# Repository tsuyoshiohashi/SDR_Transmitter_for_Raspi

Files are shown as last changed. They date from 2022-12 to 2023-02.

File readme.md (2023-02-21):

# Changes
psk_raspi.py : Added pi/2 shift BPSK, pi/4 shift QPSK and OQPSK to the modulation method.

sdr_transmitter_raspy.py : Aligned with the change of psk_raspi.py

readme.md / readme_JP.md : Updated according to the review of the description and the addition of the modulation method.

# SDR Transmitter for Raspi
RaspberryPi and an extension board (All mode transmitter HAT,self-made) perform modulation such as PSK/QPSK with SDR in the 430Mhz band etc. and output high frequency.

## Confirmed environment
Raspi3B+　Raspberry Pi OS(bullseye)

# HAT configuration and operation
## IQ signal
The IQ signal is output to Raspi's I2S and converted to a differential analog signal by the stereo DAC CS4350.
The CS4350 supports up to 192kHz sampling.

In the current version, there is a capacitor in the path of the IQ signal, so it is not possible to send DC.
In other words, it is not possible to send data that has a long series of 0's or 1's.
Usually there is an inversion for bit synchronization, so this shouldn't be a problem.

Also, modulation that requires a DC component cannot be performed.
(For example, BPSK whose phase shift is smaller than 180 degrees)

Since it is IQ modulation, the magnitude of the high frequency output can be changed according to the magnitude of the IQ signal.
The magnitude of the IQ signal can be set by software. (like volume)

If the IQ signal is made too large, it will be distorted, so please use it to make it smaller.

## Modulation/VCO/PLL

TI's trf372017 is used.
According to the datasheet, the trf372017 is an IC chip for 3G/4G with built-in IQ modulator, VCO, and PLL, and can obtain high-frequency signals modulated by IQ signals.
Control of trf372017 is via SPI.

Since the minimum frequency of VCO is 300MHz, transmission in the 144MHz band is not possible. (Upper spec is 4.8GHz, more than enough for me)
The 430MHz band can be transmitted in 10kHz steps.

Please refer to trf372017_PLL.png when changing the transmission frequency and step frequency.
The bandwidth of the IQ modulator is 160MHz, but it is used very little. 192k/160M=0.12%.....

I haven't measured the high frequency output, but it should be less than 10dBm. (P1dB=11dBm)

For details, see the circuit diagram and board diagram.

# Software
You can choose between Gnuradio version and python version for generating and transmitting modulated signals.
they are not the same.

# python version

Run sdr_transmitter_raspi.py from the command line.
~~~
$ python sdr_transmitter_raspy.py
~~~

You can enter commands when the frequency prompt appears. D2 LED will be green if the PLL is locked and red if it is unlocked. The numbers are the frequencies in steps of the transmission frequency.
"help" displays a list of commands.

In the python version, in addition to 10 types from bpsk16kbps to qpsk128kbps, you can choose each speed of pi/2 shift bpsk and pi/4 shift qpsk and OQPSK.

OQPSK is limited to 64kbps due to staggering.

The following is an example of operation.

~~~

$ python sdr_transmitter_raspi.py
SDR Transmitter for Raspi(trf372017) 192k sampling, pi shift Rev.k
SPI BUS: 0  DEV: 0
Execute VCO freq Auto-Calibration: 1
NINT= 43392
43392>data r
Data type: random
43392>len 4096
bit length= 4096
43392>repeat 2
repeat= 2
43392>freq 43393
NINT= 43393
43393>tx bpsk32
modulation type: bpsk32
Tranmit w/ bpsk32 4096 bits 2 times
fs= 192000 sps= 6
bits= 4096 symbols= 4096 samples= 24641 time=  0.12833854166666667
fs= 192000 sps= 6
bits= 4096 symbols= 4096 samples= 24641 time=  0.12833854166666667
43393>tx pi4qpsk64
modulation type: pi4qpsk64
Tranmit w/ pi4qpsk64 4096 bits 2 times
fs= 192000 sps= 6
bits= 4096 symbols= 2048 samples= 12353 time=  0.06433854166666667
fs= 192000 sps= 6
bits= 4096 symbols= 2048 samples= 12353 time=  0.06433854166666667
43393>q
Bye!

~~~

With the current settings, the transmission frequency can be set in 10kHz steps in the 430MHz band. (Integer Mode only)

You can change the frequency and steps by changing the settings, but in that case you may need to change the constants of the circuit. See the trf372017 datasheet for details.

Note that this software does not support read-back of SPI registers and cannot be read.

You can also run psk_raspi.py alone. It does not transmit with trf372017, but displays the IQ waveform etc. See the source for details.

## Gnuradio version

I confirmed the operation with Ver3.8.

Open the flow graph bpsk.grc with Gnuradio. This is a sample to send at bpsk 64kbps.

Set trf372017 such as frequency with EmbeddedBlock(Ctrl trf372017).
Modify the sample project bpsk.grc or copy and paste EmbddedBlock(Ctrl trf372017) in your project.

Send the generated IQ signal to the Audio Sink, and set the Sample Rate to 48kHz, 96kHz, or 192kHz.

3 samples/symbol at 192kHz sampling results in 64k symbols/second.

# Installation instructions

## raspi
1. /boot/config.txt

Edit /boot/config.txt to enable SPI and I2S and enable I2S driver.

Relevant parts of /boot/config.txt
~~~
dtparam=i2s=on
dtoverlay=hifiberry-dac
dtparam=spi=on
~~~

In addition, it is a good idea to disable the headphone jack and HDMI output unless there is a particular reason.
You can make a sound for confirmation, but please turn down the volume.
(The IQ signal is high resolution, but it's not pleasant music! Please be careful not to damage your ears.)

Set the I2S output as the default for the sound device.
You can check the playback device with aplay -l.

If you have multiple playback devices, set the I2S output HifiBerry to default.

2. Module installation

    The python version requires the installation of libraries and modules

~~~
$ sudo apt install libatlas-base-dev 
$ sudo apt install libportaudio2 libportaudiocpp0 portaudio19-dev 
$ pip install spidev matplotlib scikit-commpy pyaudio sounddevice 
~~~

If you have a messege the version of numpy is different

~~~
$ sudo pip install numpy --upgrade 
~~~

For the Gnuradio version, first install Gnuradio.

~~~
sudo apt install gnuradio
~~~

3.8.2 entered in my environment.

Pass PYTHONPATH for Embedded Block.

~~~
$ cd
$ nano .profile
~~~

Add the following at the end (just an example)

~~~
# trf372017 python module path
export PYTHONPATH="/home/hogehoge/sdr_tx:$PYTHONPATH"
~~~ 

The required libraries and modules may differ depending on the environment.

# Execution
    
##  For Gnuradio
Place the necessary files in any directory path set.

Required files:
bpsk.grc epy_block_0.py trf372017_raspi.py

Open bpsk.grc from Gnuradio-Companion and run it.

## For Python

Required files:
sdr_transmitter_raspi.py trf372017_raspi.py psk_raspi.py

Open a terminal and run sdr_transmitter_raspi.py.

~~~
$ python sdr_transmitter_raspi.py
~~~

Once the initialization is complete and the prompt appears, you can enter commands to configure and send.
The command list is displayed by help.
You can use the history function. You will have a .ctrl_trf_history file in your home directory.

Have A Fun!

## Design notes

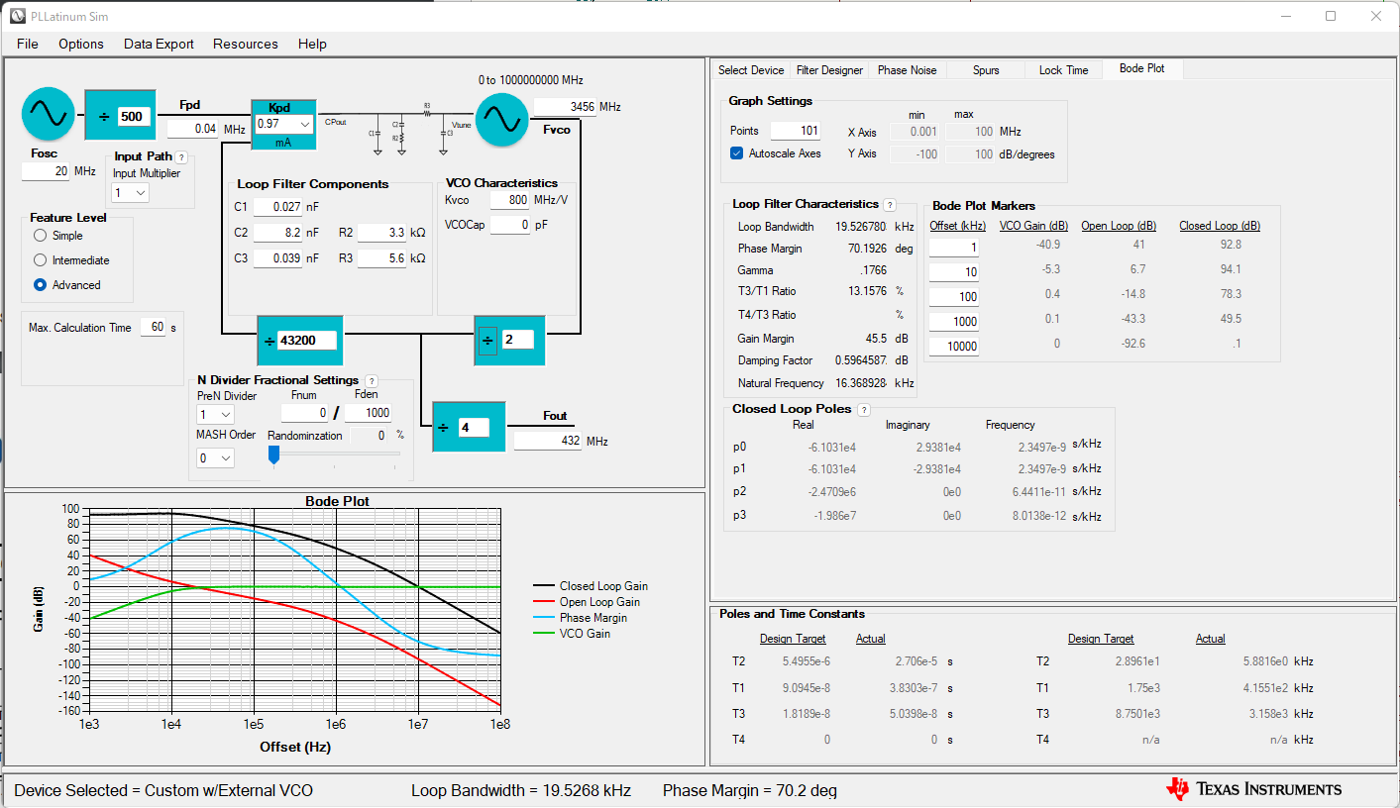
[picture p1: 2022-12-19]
hat/trf372017_PLL.png

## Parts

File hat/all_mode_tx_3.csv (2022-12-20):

Source: | KiCad\6.0\projects\all_mode_tx\all_mode_tx_3\all_mode_tx_3.kicad_sch
Date: | 2022/12/7 8:06
Tool: | Eeschema (6.0.7)
Generator: | C:\Program Files\KiCad\6.0\bin\scripting\plugins/bom_csv_grouped_by_value.py
Component Count: | 123
Individual Components:
Item | Qty | Reference(s) | Value | LibPart | Footprint | Datasheet
 |  | C1 | 10u | Device:C | Capacitor_SMD:C_0603_1608Metric_Pad1.08x0.95mm_HandSolder | ~
 |  | C2 | 104 | Device:C | Capacitor_SMD:C_0603_1608Metric_Pad1.08x0.95mm_HandSolder | ~
 |  | C3 | 10u | Device:C | Capacitor_SMD:C_0603_1608Metric_Pad1.08x0.95mm_HandSolder | ~
 |  | C4 | 104 | Device:C_Small | Capacitor_SMD:C_0603_1608Metric_Pad1.08x0.95mm_HandSolder | ~
 |  | C5 | 104 | Device:C_Small | Capacitor_SMD:C_0603_1608Metric_Pad1.08x0.95mm_HandSolder | ~
 |  | C6 | 104 | Device:C | Capacitor_SMD:C_0603_1608Metric_Pad1.08x0.95mm_HandSolder | ~
 |  | C7 | 104 | Device:C | Capacitor_SMD:C_0603_1608Metric_Pad1.08x0.95mm_HandSolder | ~
 |  | C8 | 474 | Device:C | Capacitor_SMD:C_0603_1608Metric_Pad1.08x0.95mm_HandSolder | ~
 |  | C9 | 2.2p | Device:C | Capacitor_SMD:C_0603_1608Metric_Pad1.08x0.95mm_HandSolder | ~
 |  | C10 | 2.2p | Device:C | Capacitor_SMD:C_0603_1608Metric_Pad1.08x0.95mm_HandSolder | ~
 |  | C11 | 2.7p | Device:C | Capacitor_SMD:C_0603_1608Metric_Pad1.08x0.95mm_HandSolder | ~
 |  | C12 | 2.7p | Device:C | Capacitor_SMD:C_0603_1608Metric_Pad1.08x0.95mm_HandSolder | ~
 |  | C13 | 221 | Device:C | Capacitor_SMD:C_0603_1608Metric_Pad1.08x0.95mm_HandSolder | ~
 |  | C14 | 4.7u | Device:C | Capacitor_SMD:C_0603_1608Metric_Pad1.08x0.95mm_HandSolder | ~
 |  | C15 | 4.7u | Device:C | Capacitor_SMD:C_0603_1608Metric_Pad1.08x0.95mm_HandSolder | ~
 |  | C16 | 4.7u | Device:C | Capacitor_SMD:C_0603_1608Metric_Pad1.08x0.95mm_HandSolder | ~
 |  | C17 | 4.7u | Device:C | Capacitor_SMD:C_0603_1608Metric_Pad1.08x0.95mm_HandSolder | ~
 |  | C18 | 27p | Device:C | Capacitor_SMD:C_0603_1608Metric_Pad1.08x0.95mm_HandSolder | ~
 |  | C19 | 103 | Device:C | Capacitor_SMD:C_0603_1608Metric_Pad1.08x0.95mm_HandSolder | ~
 |  | C20 | 39p | Device:C | Capacitor_SMD:C_0603_1608Metric_Pad1.08x0.95mm_HandSolder | ~
 |  | C21 | 10p | Device:C | Capacitor_SMD:C_0603_1608Metric_Pad1.08x0.95mm_HandSolder | ~
 |  | C22 | 100p | Device:C_Small | Capacitor_SMD:C_0603_1608Metric_Pad1.08x0.95mm_HandSolder | ~
 |  | C23 | 1u | Device:C_Small | Capacitor_SMD:C_0603_1608Metric_Pad1.08x0.95mm_HandSolder | ~
 |  | C24 | 100p | Device:C_Small | Capacitor_SMD:C_0603_1608Metric_Pad1.08x0.95mm_HandSolder | ~
 |  | C25 | 100p | Device:C_Small | Capacitor_SMD:C_0603_1608Metric_Pad1.08x0.95mm_HandSolder | ~
 |  | C26 | 4.7p | Device:C_Small | Capacitor_SMD:C_0603_1608Metric_Pad1.08x0.95mm_HandSolder | ~
 |  | C27 | 102 | Device:C_Small | Capacitor_SMD:C_0603_1608Metric_Pad1.08x0.95mm_HandSolder | ~
 |  | C28 | 4.7p | Device:C_Small | Capacitor_SMD:C_0603_1608Metric_Pad1.08x0.95mm_HandSolder | ~
 |  | C29 | 4.7p | Device:C_Small | Capacitor_SMD:C_0603_1608Metric_Pad1.08x0.95mm_HandSolder | ~
 |  | C30 | 4.7p | Device:C_Small | Capacitor_SMD:C_0603_1608Metric_Pad1.08x0.95mm_HandSolder | ~
 |  | C31 | 100p | Device:C | Capacitor_SMD:C_0603_1608Metric_Pad1.08x0.95mm_HandSolder | ~
 |  | C32 | 100p | Device:C_Small | Capacitor_SMD:C_0603_1608Metric_Pad1.08x0.95mm_HandSolder | ~
 |  | C33 | 4.7p | Device:C_Small | Capacitor_SMD:C_0603_1608Metric_Pad1.08x0.95mm_HandSolder | ~
 |  | C34 | 4.7p | Device:C_Small | Capacitor_SMD:C_0603_1608Metric_Pad1.08x0.95mm_HandSolder | ~
 |  | C35 | 47p | Device:C_Small | Capacitor_SMD:C_0603_1608Metric_Pad1.08x0.95mm_HandSolder | ~
 |  | C36 | 4.7p | Device:C_Small | Capacitor_SMD:C_0603_1608Metric_Pad1.08x0.95mm_HandSolder | ~
 |  | C37 | 1u | Device:C_Small | Capacitor_SMD:C_0603_1608Metric_Pad1.08x0.95mm_HandSolder | ~
 |  | C38 | 1u | Device:C_Small | Capacitor_SMD:C_0603_1608Metric_Pad1.08x0.95mm_HandSolder | ~
 |  | C39 | 1u | Device:C_Small | Capacitor_SMD:C_0603_1608Metric_Pad1.08x0.95mm_HandSolder | ~
 |  | C40 | 10u | Device:C | Capacitor_SMD:C_0603_1608Metric_Pad1.08x0.95mm_HandSolder | ~
 |  | C41 | 3.3 | Device:C | Capacitor_SMD:C_0603_1608Metric_Pad1.08x0.95mm_HandSolder | ~
 |  | C42 | 104 | Device:C | Capacitor_SMD:C_0603_1608Metric_Pad1.08x0.95mm_HandSolder | ~
 |  | C43 | 10u | Device:C | Capacitor_SMD:C_0603_1608Metric_Pad1.08x0.95mm_HandSolder | ~
 |  | C44 | 104 | Device:C | Capacitor_SMD:C_0603_1608Metric_Pad1.08x0.95mm_HandSolder | ~
 |  | C45 | 10u | Device:C | Capacitor_SMD:C_0603_1608Metric_Pad1.08x0.95mm_HandSolder | ~
 |  | C46 | 104 | Device:C | Capacitor_SMD:C_0603_1608Metric_Pad1.08x0.95mm_HandSolder | ~
 |  | C47 | 104 | Device:C | Capacitor_SMD:C_0603_1608Metric_Pad1.08x0.95mm_HandSolder | ~
 |  | D1 | PWR | Device:LED | LED_SMD:LED_0603_1608Metric_Pad1.05x0.95mm_HandSolder | ~
 |  | D2 | LD | Device:LED | LED_SMD:LED_0603_1608Metric_Pad1.05x0.95mm_HandSolder | ~
 |  | FB1 | 1k | Device:FerriteBead_Small | Inductor_SMD:L_0603_1608Metric_Pad1.05x0.95mm_HandSolder | ~
 |  | FB2 | 1k | Device:FerriteBead_Small | Inductor_SMD:L_0603_1608Metric_Pad1.05x0.95mm_HandSolder | ~
 |  | FB3 | 1k | Device:FerriteBead_Small | Inductor_SMD:L_0603_1608Metric_Pad1.05x0.95mm_HandSolder | ~
 |  | FB4 | 1k | Device:FerriteBead_Small | Inductor_SMD:L_0603_1608Metric_Pad1.05x0.95mm_HandSolder | ~
 |  | FB5 | 1k | Device:FerriteBead_Small | Inductor_SMD:L_0603_1608Metric_Pad1.05x0.95mm_HandSolder | ~
 |  | FB6 | 1k | Device:FerriteBead_Small | Inductor_SMD:L_0603_1608Metric_Pad1.05x0.95mm_HandSolder | ~
 |  | FB7 | 1k | Device:FerriteBead_Small | Inductor_SMD:L_0603_1608Metric_Pad1.05x0.95mm_HandSolder | ~
 |  | FB8 | 1k | Device:FerriteBead_Small | Inductor_SMD:L_0603_1608Metric_Pad1.05x0.95mm_HandSolder | ~
 |  | FB9 | DNI | Device:FerriteBead_Small | Inductor_SMD:L_0603_1608Metric_Pad1.05x0.95mm_HandSolder | ~
 |  | J1 | GPIO | Connector_Generic:Conn_02x20_Odd_Even | Connector_PinSocket_2.54mm:PinSocket_2x20_P2.54mm_Vertical | ~
 |  | J2 | SMA | Connector:Conn_Coaxial | Connector_Coaxial:SMA_Molex_73251-1153_EdgeMount_Horizontal | ~
 |  | L1 | 68n | Device:L | Inductor_SMD:L_0603_1608Metric_Pad1.05x0.95mm_HandSolder | ~
 |  | L2 | 68n | Device:L | Inductor_SMD:L_0603_1608Metric_Pad1.05x0.95mm_HandSolder | ~
 |  | L3 | 68n | Device:L | Inductor_SMD:L_0603_1608Metric_Pad1.05x0.95mm_HandSolder | ~
 |  | L4 | 68n | Device:L | Inductor_SMD:L_0603_1608Metric_Pad1.05x0.95mm_HandSolder | ~
 |  | L5 | 10n | Device:L | Inductor_SMD:L_0603_1608Metric_Pad1.05x0.95mm_HandSolder | ~
 |  | L6 | 10n | Device:L | Inductor_SMD:L_0603_1608Metric_Pad1.05x0.95mm_HandSolder | ~
 |  | L7 | 10n | Device:L | Inductor_SMD:L_0603_1608Metric_Pad1.05x0.95mm_HandSolder | ~
 |  | L8 | 10n | Device:L | Inductor_SMD:L_0603_1608Metric_Pad1.05x0.95mm_HandSolder | ~
 |  | Q1 | Q_NMOS_GSD | Device:Q_NMOS_GSD | Package_TO_SOT_SMD:SOT-23 | ~
 |  | R1 | 331 | Device:R | Resistor_SMD:R_0603_1608Metric_Pad0.98x0.95mm_HandSolder | ~
 |  | R2 | 4.7k | Device:R_Small | Resistor_SMD:R_0603_1608Metric_Pad0.98x0.95mm_HandSolder | ~
 |  | R3 | 4.7k | Device:R_Small | Resistor_SMD:R_0603_1608Metric_Pad0.98x0.95mm_HandSolder | ~
 |  | R4 | 4.7k | Device:R_Small | Resistor_SMD:R_0603_1608Metric_Pad0.98x0.95mm_HandSolder | ~
 |  | R5 | 4.7k | Device:R_Small | Resistor_SMD:R_0603_1608Metric_Pad0.98x0.95mm_HandSolder | ~
 |  | R6 | 47 | Device:R | Resistor_SMD:R_0603_1608Metric_Pad0.98x0.95mm_HandSolder | ~
 |  | R7 | 47 | Device:R | Resistor_SMD:R_0603_1608Metric_Pad0.98x0.95mm_HandSolder | ~
 |  | R8 | 47 | Device:R | Resistor_SMD:R_0603_1608Metric_Pad0.98x0.95mm_HandSolder | ~
 |  | R9 | 60.4 | Device:R | Resistor_SMD:R_0603_1608Metric_Pad0.98x0.95mm_HandSolder | ~
 |  | R10 | 60.4 | Device:R | Resistor_SMD:R_0603_1608Metric_Pad0.98x0.95mm_HandSolder | ~
 |  | R11 | 60.4 | Device:R | Resistor_SMD:R_0603_1608Metric_Pad0.98x0.95mm_HandSolder | ~
 |  | R12 | 60.4 | Device:R | Resistor_SMD:R_0603_1608Metric_Pad0.98x0.95mm_HandSolder | ~
 |  | R13 | 0 | Device:R | Resistor_SMD:R_0603_1608Metric_Pad0.98x0.95mm_HandSolder | ~
 |  | R14 | 90.9 | Device:R | Resistor_SMD:R_0603_1608Metric_Pad0.98x0.95mm_HandSolder | ~
 |  | R15 | 90.9 | Device:R | Resistor_SMD:R_0603_1608Metric_Pad0.98x0.95mm_HandSolder | ~
 |  | R16 | 47 | Device:R | Resistor_SMD:R_0603_1608Metric_Pad0.98x0.95mm_HandSolder | ~
 |  | R17 | 47 | Device:R | Resistor_SMD:R_0603_1608Metric_Pad0.98x0.95mm_HandSolder | ~
 |  | R18 | 3.3k | Device:R | Resistor_SMD:R_0603_1608Metric_Pad0.98x0.95mm_HandSolder | ~
 |  | R19 | 2.2k | Device:R_Small | Resistor_SMD:R_0603_1608Metric_Pad0.98x0.95mm_HandSolder | ~
 |  | R20 | 10k | Device:R_Small | Resistor_SMD:R_0603_1608Metric_Pad0.98x0.95mm_HandSolder | ~
 |  | R21 | 5.6k | Device:R | Resistor_SMD:R_0603_1608Metric_Pad0.98x0.95mm_HandSolder | ~
 |  | R22 | 271 | Device:R | Resistor_SMD:R_0603_1608Metric_Pad0.98x0.95mm_HandSolder | ~
 |  | R23 | 50 | Device:R | Resistor_SMD:R_0603_1608Metric_Pad0.98x0.95mm_HandSolder | ~
 |  | R24 | 33 | Device:R | Resistor_SMD:R_0603_1608Metric_Pad0.98x0.95mm_HandSolder | ~
 |  | R25 | 33 | Device:R | Resistor_SMD:R_0603_1608Metric_Pad0.98x0.95mm_HandSolder | ~
 |  | R26 | 33 | Device:R | Resistor_SMD:R_0603_1608Metric_Pad0.98x0.95mm_HandSolder | ~
 |  | R27 | 10k | Device:R | Resistor_SMD:R_0603_1608Metric_Pad0.98x0.95mm_HandSolder | ~
 |  | R28 | 10k | Device:R | Resistor_SMD:R_0603_1608Metric_Pad0.98x0.95mm_HandSolder | ~
 |  | R29 | 10k | Device:R | Resistor_SMD:R_0603_1608Metric_Pad0.98x0.95mm_HandSolder | ~
 |  | R30 | 10k | Device:R | Resistor_SMD:R_0603_1608Metric_Pad0.98x0.95mm_HandSolder | ~
 |  | TP1 | BBI- | Connector:TestPoint | TestPoint:TestPoint_Pad_D2.0mm | ~
 |  | TP2 | BBI+ | Connector:TestPoint | TestPoint:TestPoint_Pad_D2.0mm | ~
 |  | TP3 | BBQ- | Connector:TestPoint | TestPoint:TestPoint_Pad_D2.0mm | ~
 |  | TP4 | BBQ+ | Connector:TestPoint | TestPoint:TestPoint_Pad_D2.0mm | ~
 |  | TP5 | SPILE | Connector:TestPoint | TestPoint:TestPoint_Pad_D2.0mm | ~
 |  | TP6 | SPICLK | Connector:TestPoint | TestPoint:TestPoint_Pad_D2.0mm | ~
 |  | TP7 | SPIDATA | Connector:TestPoint | TestPoint:TestPoint_Pad_D2.0mm | ~
 |  | TP8 | SPIRDBK | Connector:TestPoint | TestPoint:TestPoint_Pad_D2.0mm | ~
 |  | TP9 | PLL_LD | Connector:TestPoint | TestPoint:TestPoint_Pad_D2.0mm | ~
 |  | TP10 | GND | Connector:TestPoint | TestPoint:TestPoint_Pad_D2.5mm | ~
 |  | TP11 | /RST | Connector:TestPoint | TestPoint:TestPoint_Pad_D2.0mm | ~
 |  | TP12 | SDIN | Connector:TestPoint | TestPoint:TestPoint_Pad_D2.0mm | ~
 |  | TP13 | SCLK | Connector:TestPoint | TestPoint:TestPoint_Pad_D2.0mm | ~
 |  | TP14 | LRCK | Connector:TestPoint | TestPoint:TestPoint_Pad_D2.0mm | ~
 |  | TP15 | RMCK | Connector:TestPoint | TestPoint:TestPoint_Pad_D2.0mm | ~
 |  | TP16 | B- | Connector:TestPoint | TestPoint:TestPoint_Pad_D2.0mm | ~
 |  | TP17 | B+ | Connector:TestPoint | TestPoint:TestPoint_Pad_D2.0mm | ~
 |  | TP18 | A- | Connector:TestPoint | TestPoint:TestPoint_Pad_D2.0mm | ~
 |  | TP19 | A+ | Connector:TestPoint | TestPoint:TestPoint_Pad_D2.0mm | ~
 |  | U1 | AZ1117-3.3 | Regulator_Linear:AZ1117-3.3 | Package_TO_SOT_SMD:SOT-223 | https://www.diodes.com/assets/Datasheets/AZ1117.pdf
 |  | U2 | LT6604 | My_Library2:LT6604 | MyLibrary:LT6604IUFF-2.5-PBF
 |  | U3 | TRF372017 | My_Library2:TRF372017 | Package_DFN_QFN:VQFN-48-1EP_7x7mm_P0.5mm_EP5.15x5.15mm_ThermalVias
 |  | U4 | CS4350 | My_Library2:CS4350 | Package_SO:TSSOP-24_4.4x7.8mm_P0.65mm
 |  | X1 | ASV-20.0MHz | Oscillator:ASV-xxxMHz | Oscillator:Oscillator_SMD_Abracon_ASV-4Pin_7.0x5.1mm | http://www.abracon.com/Oscillators/ASV.pdf
Collated Components:
Item | Qty | Reference(s) | Value | LibPart | Footprint | Datasheet
1 | 5 | C1, C3, C40, C43, C45 | 10u | Device:C | Capacitor_SMD:C_0603_1608Metric_Pad1.08x0.95mm_HandSolder | ~
2 | 7 | C2, C6, C7, C42, C44, C46, C47 | 104 | Device:C | Capacitor_SMD:C_0603_1608Metric_Pad1.08x0.95mm_HandSolder | ~
3 | 2 | C4, C5 | 104 | Device:C_Small | Capacitor_SMD:C_0603_1608Metric_Pad1.08x0.95mm_HandSolder | ~
4 | 1 | C8 | 474 | Device:C | Capacitor_SMD:C_0603_1608Metric_Pad1.08x0.95mm_HandSolder | ~
5 | 2 | C9, C10 | 2.2p | Device:C | Capacitor_SMD:C_0603_1608Metric_Pad1.08x0.95mm_HandSolder | ~
6 | 2 | C11, C12 | 2.7p | Device:C | Capacitor_SMD:C_0603_1608Metric_Pad1.08x0.95mm_HandSolder | ~
7 | 1 | C13 | 221 | Device:C | Capacitor_SMD:C_0603_1608Metric_Pad1.08x0.95mm_HandSolder | ~
8 | 4 | C14, C15, C16, C17 | 4.7u | Device:C | Capacitor_SMD:C_0603_1608Metric_Pad1.08x0.95mm_HandSolder | ~
9 | 1 | C18 | 27p | Device:C | Capacitor_SMD:C_0603_1608Metric_Pad1.08x0.95mm_HandSolder | ~
10 | 1 | C19 | 103 | Device:C | Capacitor_SMD:C_0603_1608Metric_Pad1.08x0.95mm_HandSolder | ~
11 | 1 | C20 | 39p | Device:C | Capacitor_SMD:C_0603_1608Metric_Pad1.08x0.95mm_HandSolder | ~
12 | 1 | C21 | 10p | Device:C | Capacitor_SMD:C_0603_1608Metric_Pad1.08x0.95mm_HandSolder | ~
13 | 4 | C22, C24, C25, C32 | 100p | Device:C_Small | Capacitor_SMD:C_0603_1608Metric_Pad1.08x0.95mm_HandSolder | ~
14 | 4 | C23, C37, C38, C39 | 1u | Device:C_Small | Capacitor_SMD:C_0603_1608Metric_Pad1.08x0.95mm_HandSolder | ~
15 | 7 | C26, C28, C29, C30, C33, C34, C36 | 4.7p | Device:C_Small | Capacitor_SMD:C_0603_1608Metric_Pad1.08x0.95mm_HandSolder | ~
16 | 1 | C27 | 102 | Device:C_Small | Capacitor_SMD:C_0603_1608Metric_Pad1.08x0.95mm_HandSolder | ~
17 | 1 | C31 | 100p | Device:C | Capacitor_SMD:C_0603_1608Metric_Pad1.08x0.95mm_HandSolder | ~
18 | 1 | C35 | 47p | Device:C_Small | Capacitor_SMD:C_0603_1608Metric_Pad1.08x0.95mm_HandSolder | ~
19 | 1 | C41 | 3.3 | Device:C | Capacitor_SMD:C_0603_1608Metric_Pad1.08x0.95mm_HandSolder | ~
20 | 1 | D1 | PWR | Device:LED | LED_SMD:LED_0603_1608Metric_Pad1.05x0.95mm_HandSolder | ~
21 | 1 | D2 | LD | Device:LED | LED_SMD:LED_0603_1608Metric_Pad1.05x0.95mm_HandSolder | ~
22 | 8 | FB1, FB2, FB3, FB4, FB5, FB6, FB7, FB8 | 1k | Device:FerriteBead_Small | Inductor_SMD:L_0603_1608Metric_Pad1.05x0.95mm_HandSolder | ~
23 | 1 | FB9 | DNI | Device:FerriteBead_Small | Inductor_SMD:L_0603_1608Metric_Pad1.05x0.95mm_HandSolder | ~
24 | 1 | J1 | GPIO | Connector_Generic:Conn_02x20_Odd_Even | Connector_PinSocket_2.54mm:PinSocket_2x20_P2.54mm_Vertical | ~
25 | 1 | J2 | SMA | Connector:Conn_Coaxial | Connector_Coaxial:SMA_Molex_73251-1153_EdgeMount_Horizontal | ~
26 | 4 | L1, L2, L3, L4 | 68n | Device:L | Inductor_SMD:L_0603_1608Metric_Pad1.05x0.95mm_HandSolder | ~
27 | 4 | L5, L6, L7, L8 | 10n | Device:L | Inductor_SMD:L_0603_1608Metric_Pad1.05x0.95mm_HandSolder | ~
28 | 1 | Q1 | Q_NMOS_GSD | Device:Q_NMOS_GSD | Package_TO_SOT_SMD:SOT-23 | ~
29 | 1 | R1 | 331 | Device:R | Resistor_SMD:R_0603_1608Metric_Pad0.98x0.95mm_HandSolder | ~
30 | 4 | R2, R3, R4, R5 | 4.7k | Device:R_Small | Resistor_SMD:R_0603_1608Metric_Pad0.98x0.95mm_HandSolder | ~
31 | 5 | R6, R7, R8, R16, R17 | 47 | Device:R | Resistor_SMD:R_0603_1608Metric_Pad0.98x0.95mm_HandSolder | ~
32 | 4 | R9, R10, R11, R12 | 60.4 | Device:R | Resistor_SMD:R_0603_1608Metric_Pad0.98x0.95mm_HandSolder | ~
33 | 1 | R13 | 0 | Device:R | Resistor_SMD:R_0603_1608Metric_Pad0.98x0.95mm_HandSolder | ~
34 | 2 | R14, R15 | 90.9 | Device:R | Resistor_SMD:R_0603_1608Metric_Pad0.98x0.95mm_HandSolder | ~
35 | 1 | R18 | 3.3k | Device:R | Resistor_SMD:R_0603_1608Metric_Pad0.98x0.95mm_HandSolder | ~
36 | 1 | R19 | 2.2k | Device:R_Small | Resistor_SMD:R_0603_1608Metric_Pad0.98x0.95mm_HandSolder | ~
37 | 1 | R20 | 10k | Device:R_Small | Resistor_SMD:R_0603_1608Metric_Pad0.98x0.95mm_HandSolder | ~
38 | 1 | R21 | 5.6k | Device:R | Resistor_SMD:R_0603_1608Metric_Pad0.98x0.95mm_HandSolder | ~
39 | 1 | R22 | 271 | Device:R | Resistor_SMD:R_0603_1608Metric_Pad0.98x0.95mm_HandSolder | ~
40 | 1 | R23 | 50 | Device:R | Resistor_SMD:R_0603_1608Metric_Pad0.98x0.95mm_HandSolder | ~
41 | 3 | R24, R25, R26 | 33 | Device:R | Resistor_SMD:R_0603_1608Metric_Pad0.98x0.95mm_HandSolder | ~
42 | 4 | R27, R28, R29, R30 | 10k | Device:R | Resistor_SMD:R_0603_1608Metric_Pad0.98x0.95mm_HandSolder | ~
43 | 1 | TP1 | BBI- | Connector:TestPoint | TestPoint:TestPoint_Pad_D2.0mm | ~
44 | 1 | TP2 | BBI+ | Connector:TestPoint | TestPoint:TestPoint_Pad_D2.0mm | ~
45 | 1 | TP3 | BBQ- | Connector:TestPoint | TestPoint:TestPoint_Pad_D2.0mm | ~
46 | 1 | TP4 | BBQ+ | Connector:TestPoint | TestPoint:TestPoint_Pad_D2.0mm | ~
47 | 1 | TP5 | SPILE | Connector:TestPoint | TestPoint:TestPoint_Pad_D2.0mm | ~
48 | 1 | TP6 | SPICLK | Connector:TestPoint | TestPoint:TestPoint_Pad_D2.0mm | ~
49 | 1 | TP7 | SPIDATA | Connector:TestPoint | TestPoint:TestPoint_Pad_D2.0mm | ~
50 | 1 | TP8 | SPIRDBK | Connector:TestPoint | TestPoint:TestPoint_Pad_D2.0mm | ~
51 | 1 | TP9 | PLL_LD | Connector:TestPoint | TestPoint:TestPoint_Pad_D2.0mm | ~
52 | 1 | TP10 | GND | Connector:TestPoint | TestPoint:TestPoint_Pad_D2.5mm | ~
53 | 1 | TP11 | /RST | Connector:TestPoint | TestPoint:TestPoint_Pad_D2.0mm | ~
54 | 1 | TP12 | SDIN | Connector:TestPoint | TestPoint:TestPoint_Pad_D2.0mm | ~
55 | 1 | TP13 | SCLK | Connector:TestPoint | TestPoint:TestPoint_Pad_D2.0mm | ~
56 | 1 | TP14 | LRCK | Connector:TestPoint | TestPoint:TestPoint_Pad_D2.0mm | ~
57 | 1 | TP15 | RMCK | Connector:TestPoint | TestPoint:TestPoint_Pad_D2.0mm | ~
58 | 1 | TP16 | B- | Connector:TestPoint | TestPoint:TestPoint_Pad_D2.0mm | ~
59 | 1 | TP17 | B+ | Connector:TestPoint | TestPoint:TestPoint_Pad_D2.0mm | ~
60 | 1 | TP18 | A- | Connector:TestPoint | TestPoint:TestPoint_Pad_D2.0mm | ~
61 | 1 | TP19 | A+ | Connector:TestPoint | TestPoint:TestPoint_Pad_D2.0mm | ~
62 | 1 | U1 | AZ1117-3.3 | Regulator_Linear:AZ1117-3.3 | Package_TO_SOT_SMD:SOT-223 | https://www.diodes.com/assets/Datasheets/AZ1117.pdf
63 | 1 | U2 | LT6604 | My_Library2:LT6604 | MyLibrary:LT6604IUFF-2.5-PBF
64 | 1 | U3 | TRF372017 | My_Library2:TRF372017 | Package_DFN_QFN:VQFN-48-1EP_7x7mm_P0.5mm_EP5.15x5.15mm_ThermalVias
65 | 1 | U4 | CS4350 | My_Library2:CS4350 | Package_SO:TSSOP-24_4.4x7.8mm_P0.65mm
66 | 1 | X1 | ASV-20.0MHz | Oscillator:ASV-xxxMHz | Oscillator:Oscillator_SMD_Abracon_ASV-4Pin_7.0x5.1mm | http://www.abracon.com/Oscillators/ASV.pdf

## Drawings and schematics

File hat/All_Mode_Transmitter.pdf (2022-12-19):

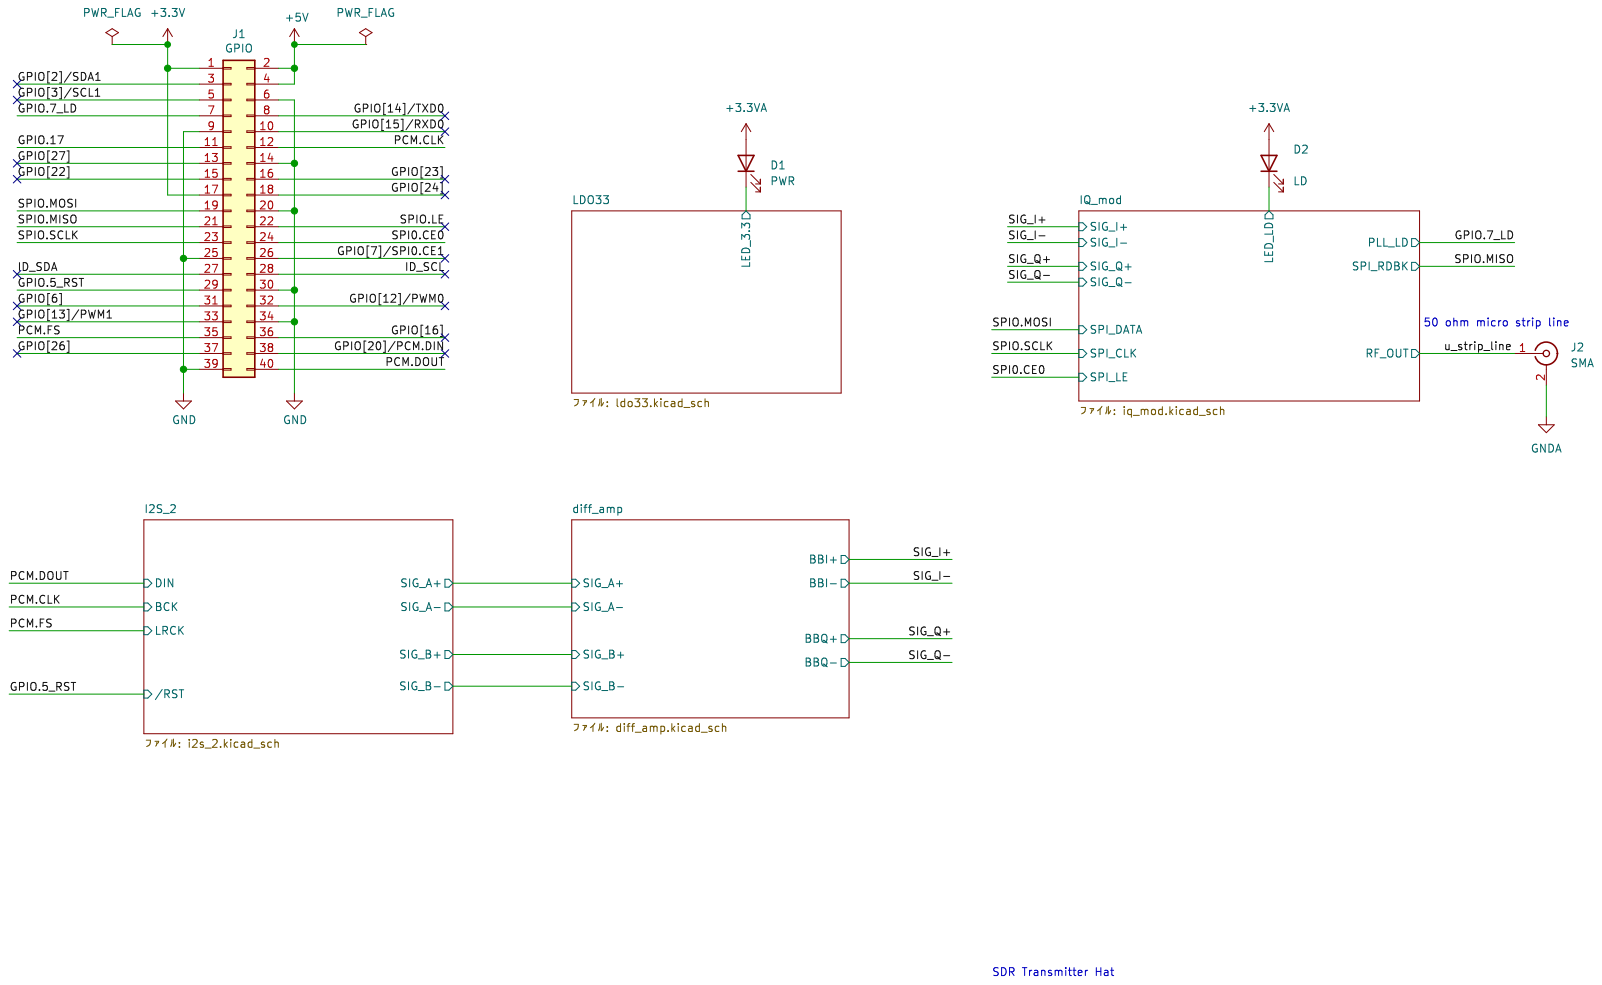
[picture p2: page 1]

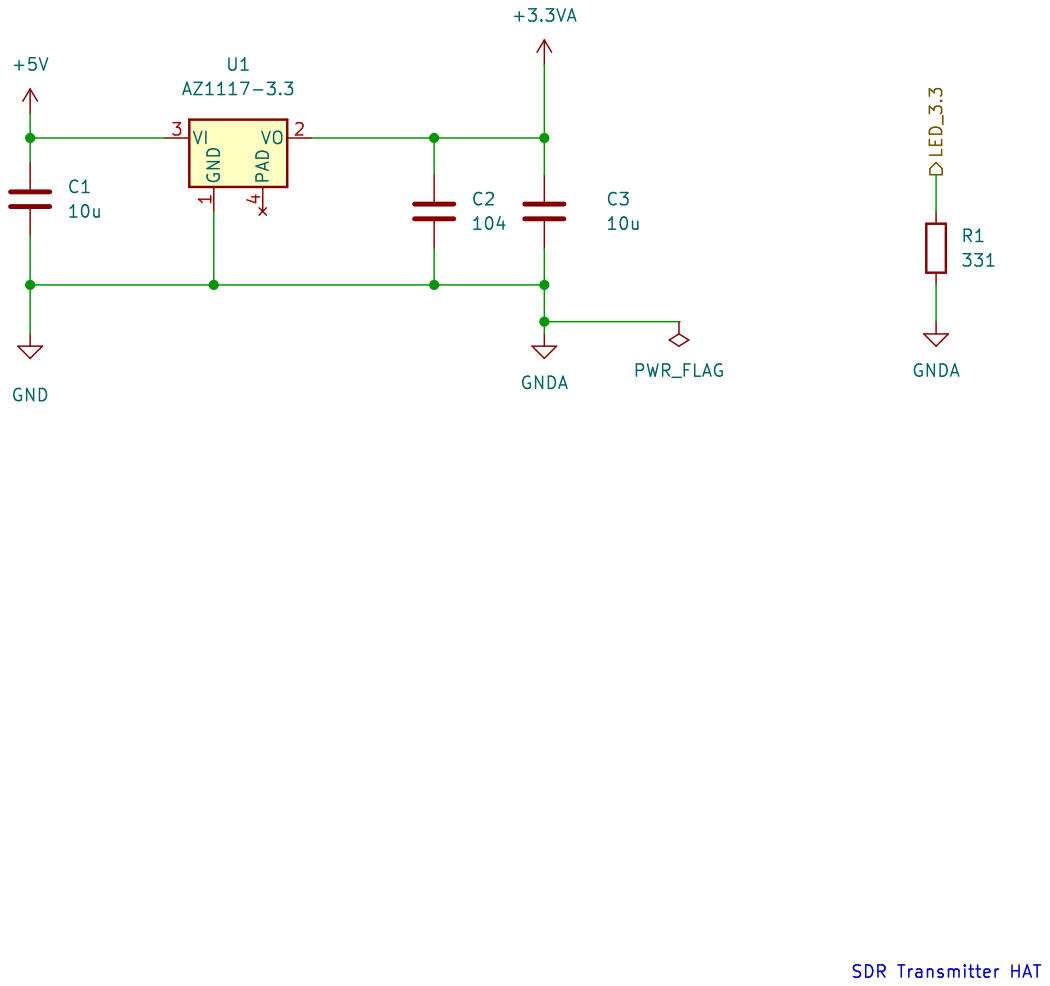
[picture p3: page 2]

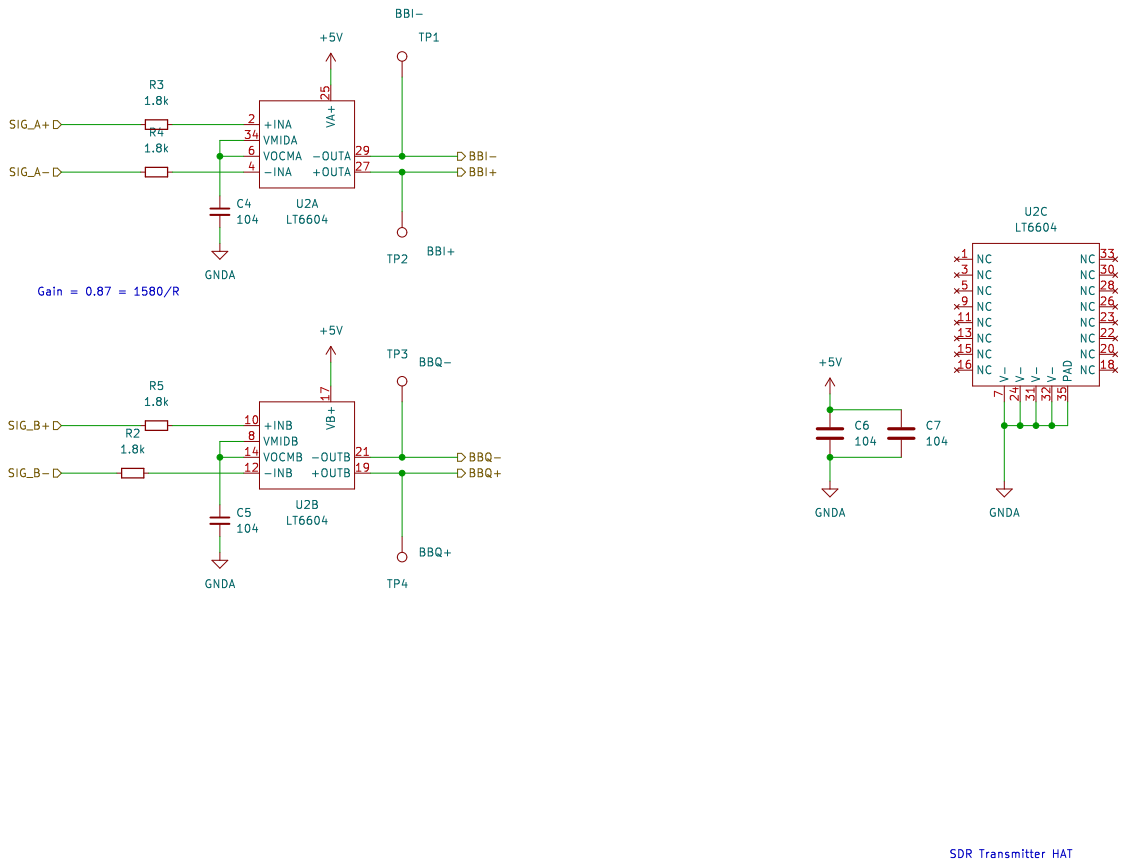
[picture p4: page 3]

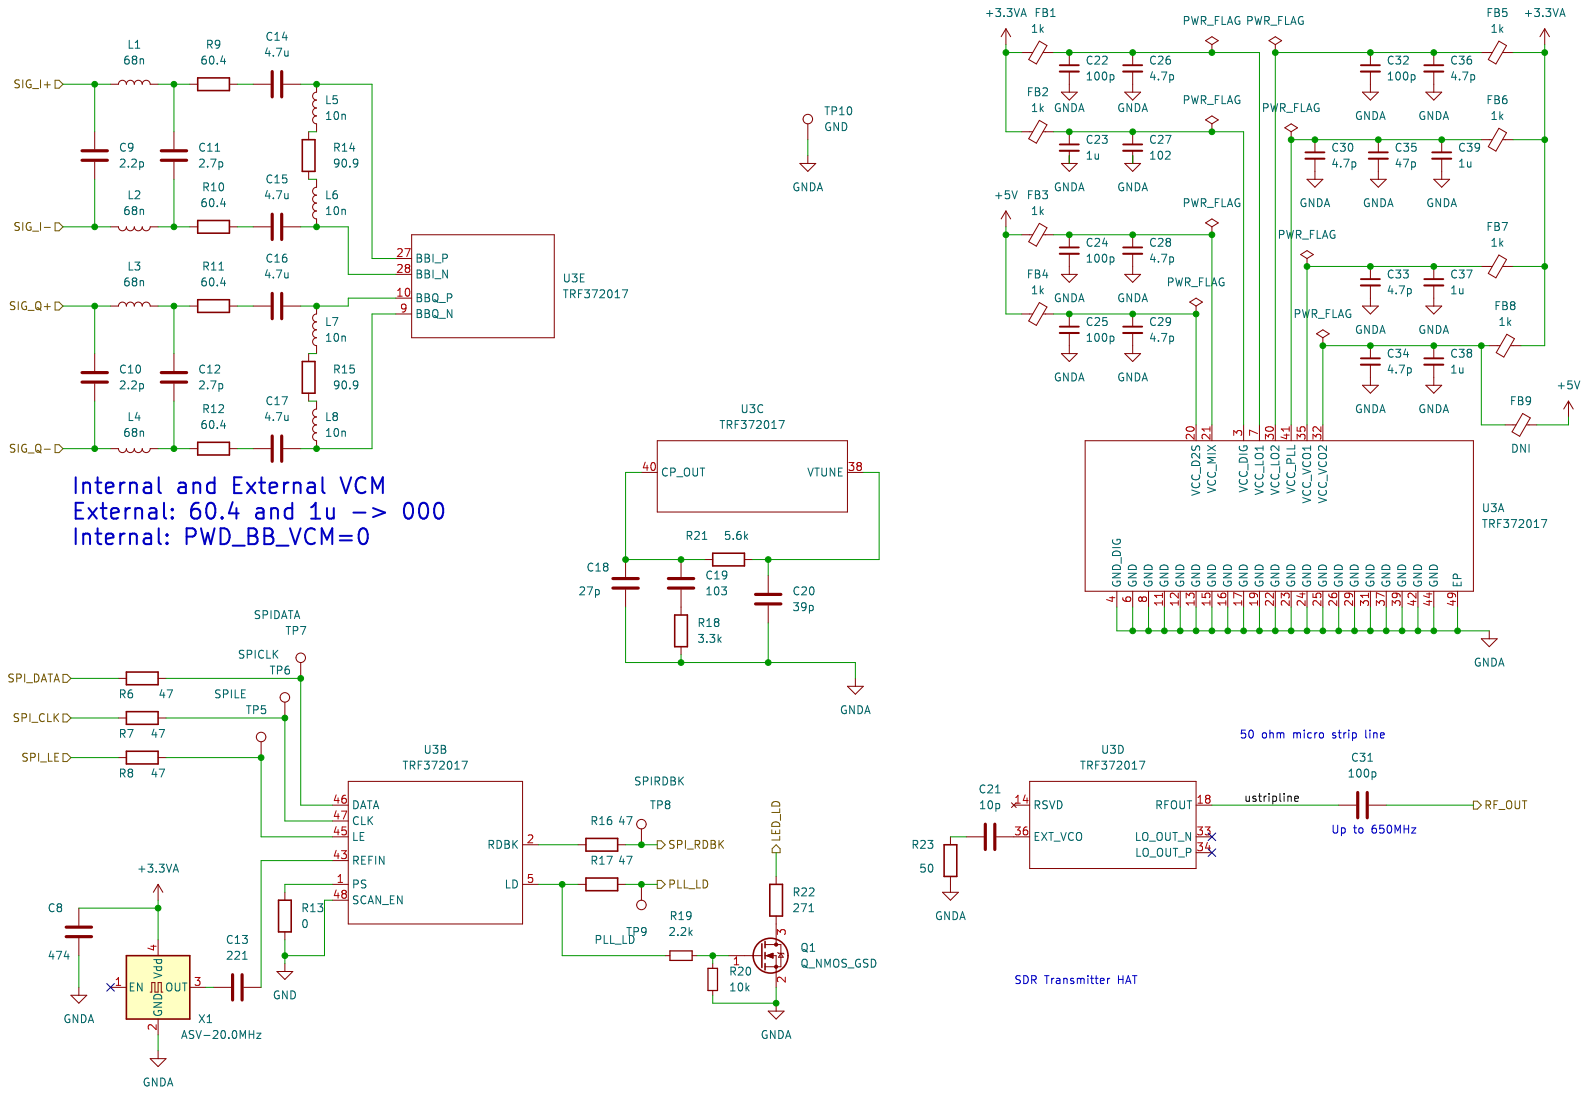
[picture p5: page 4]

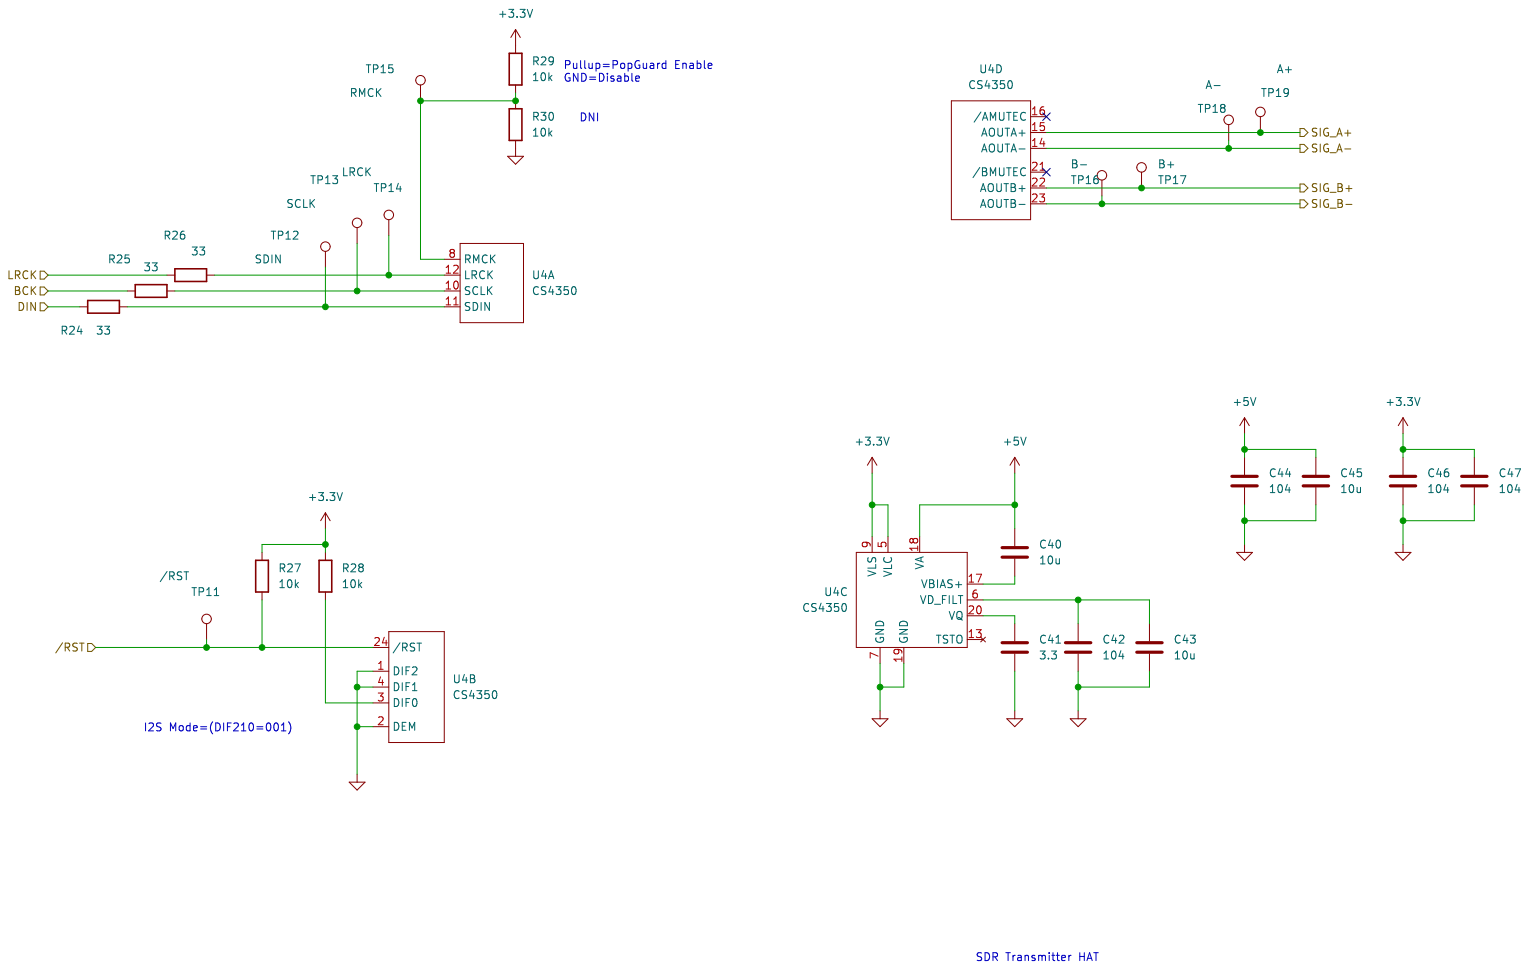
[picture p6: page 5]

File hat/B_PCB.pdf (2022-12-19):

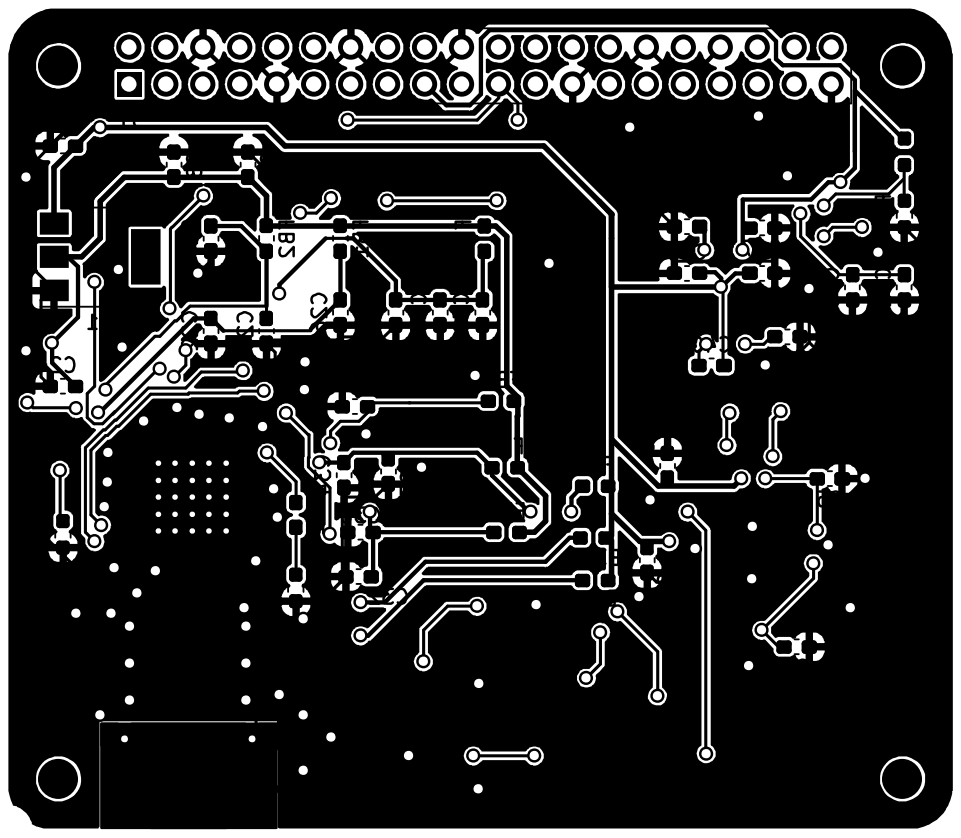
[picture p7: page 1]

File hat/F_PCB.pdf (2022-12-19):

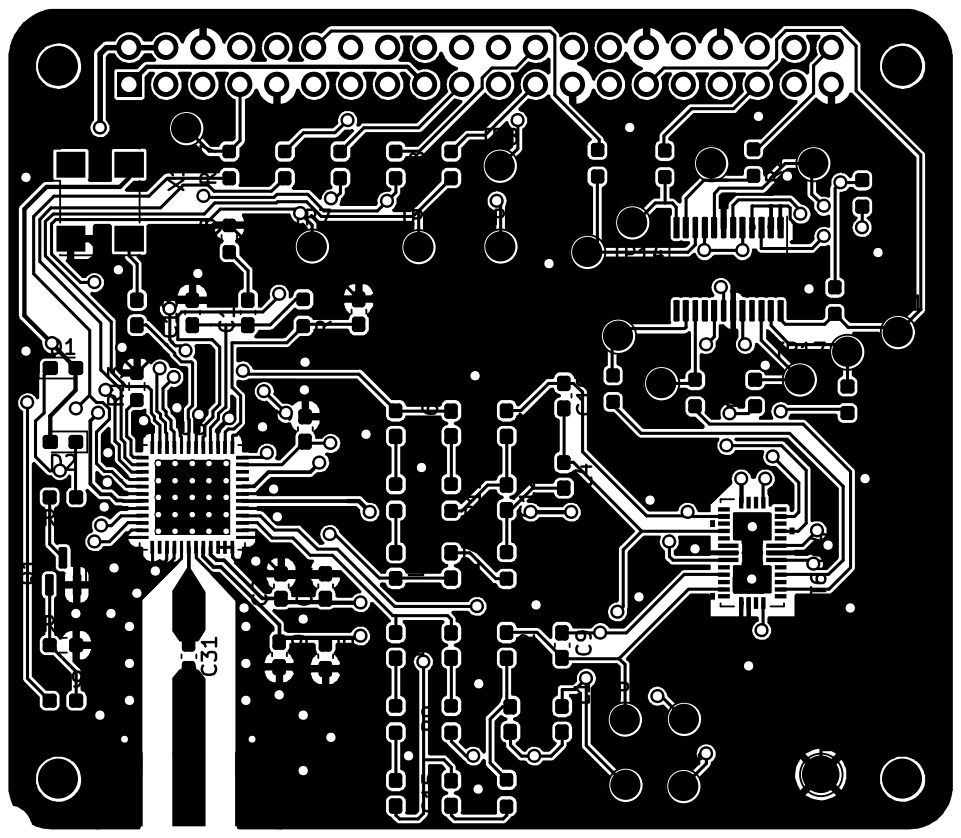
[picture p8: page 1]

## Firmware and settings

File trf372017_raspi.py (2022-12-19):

#!/usr/bin/env python3
# -*- coding: utf-8 -*-
#
# trf372017_raspi.py
#
# Data sheet: https://www.ti.com/product/TRF372017
#
# This program is for SDR_Transmit_Hat(My own work)
# set registers in trf372017 to control VCO and PLL
# 
# SPI and I2S port in raspi board must be enabled. 
#
# Required file: sdr_transmitter_raspi.py and psk_raspi.py in the same directory
#
# This implementation is for personal experiments.
#
# Copyright (c) 2022 Tsuyoshi Ohashi
# Released under the MIT license
# https://opensource.org/licenses/mit-license.php
# 

import spidev
import RPi.GPIO as GPIO
from time import sleep

class Trf372017:
    # lock detect port
    lock_detect_port = 4    # GPIO4,pin7
    # Frequency Range   10kHz Step
    nint_min = 43001    # 430.01 MHz
    nint_max = 43999    # 439.99 MHz
    freq_default = 43392    # 433.92MHz
    freq_step = 10000       # 10kHz
    # Register 1
    rdiv = 500      # 20MHz(fREF_OSC)/40kHz(fPFD) = 500
    ref_inv = 0     # up edge
    neg_vco = 1     # negative slope
    icp = 0b01010   # 0.97mA
    icpdouble = 0   # not double
    cal_clk_sel = 0x3   # Scaling Factor is 16 (Table.13)
                        # fPFD is 40kHz, CAL_CLK_FREQUENCY is 640kHz > 0.1MHz 
    rsv = 0
    # Register 2
    nint = 43392        # fRF=430-440MHz,fRFSTEPSIZE=10kHz
    pll_div_sel = 0b01  # PLL FREQUENCY DIVIDER is 2
    prsc_sel = 1    # 1, 1->8/9, 0->4/5
    vco_sel = 0b00  # lowest frequency
    vcosel_mode = 0 # Auto select vco and capacitor
    cal_acc = 0b00  # error count
    en_cal = 0      # Execute VCO auto-cal
    # Register 3 
    nfrac = 0x00    # disuse
    # Register 4
    pwd_pll = 0     # on
    pwd_cp = 0      # on
    pwd_vco = 0     # on
    pwd_vcomux = 0  # on
    pwd_div124 =0   # on
    pwd_presc = 0   # on
    pwd_out_buff = 1    # off  LO output buffer, disuse
    pwd_lo_div = 1  # off, disuse
    pwd_tx_div = 1  # off, 
    pwd_bb_vcm = 0  # OFF(1): VCM Disable, ON(0) VCM Enable
    pwd_dc_off = 1  # OFF
    en_ext_vco = 0  # disable
    en_isource = 0  # off fractional mode only
    ld_ana_prec = 0b11  # integer mode=00  # LOW(11) better??
    cp_tristate = 0b00  # Normal
    speedup = 0
    ld_dig_prec = 1 # 0: normal, 1:long time
    en_dith = 1     # 
    mod_ord = 0b01  # DISUSE
    dith_sel = 0
    del_sd_clk = 0b01   # DISUSE
    en_frac = 0     # No, 
    # Register 5
    vcobias_rtrim = 0b100
    pllbias_rtrim = 0b10
    vco_bias = 0b0101   # 400uA,VCC_VCO2=3.3V
    vcobuf_bias = 0b10
    vcomux_bias = 0b11
    bufout_bias = 0b00      # LO OUT
    vco_cal_ib = 0
    vco_cal_ref = 0b010
    vco_ampl_ctrl = 0b11
    vco_vb_ctrl = 0b00
    en_ld_isource = 0
    # Register 6
    ioff = 0x80
    qoff = 0x80
    vref_sel = 0b100    # recommended[100], 0.65V[000], 1V[111]
    tx_div_sel = 0b11   # Div8
    lo_div_sel = 0b11   # Div8
    tx_div_bias = 0b10  # 50uA
    lo_div_bias = 0b10  # 50uA
    # Register 7
    vco_trim = 0x20     # used in manual cal mode
    vco_test_mode = 0
    cal_bypass = 0
    mux_ctrl = 0b001    # Lock Detect pin5
    isource_sink = 0
    isource_trim = 0b100
    pd_tc = 0b00
    ib_vcm_sel = 0  # PTAT(Proportional To Absolute Temperature) recommended
    dcoffset_i = 0b10   # 150uA input DC offset
    vco_bias_sel = 1    #
    # Register 0
    count_mode_mux_sel = 0  # minimun frequency( target is 430MHz band)
    
    # CS4350 /RESET port
    cs_reset_port = 5   # GPIO5,pin29
    
    def __init__(self, bus=0, dev=0):
        
        try:
            self.spi = spidev.SpiDev()
            self.spi.open(bus, dev)
            self.spi.max_speed_hz = 100000  # 100khz
            self.spi.mode = 0
            print("SPI BUS:", bus, " DEV:", dev)
        except:
            print("SPI Error")
            exit(1)
            
        # port numbering, bcm mode
        GPIO.setmode(GPIO.BCM)
        # init lock detect io port
        GPIO.setup(self.lock_detect_port, GPIO.IN)
        
        # init CS4350 Reset port
        GPIO.setup(self.cs_reset_port, GPIO.OUT)
        sleep(0.5)
        GPIO.output(self.cs_reset_port, GPIO.LOW )
        sleep(0.5)
        GPIO.output(self.cs_reset_port, GPIO.HIGH )
        
        # set registers default 
        self.set_reg1()
        self.set_reg2()
        self.set_reg4()
        self.set_reg5()
        self.set_reg6()
        self.set_reg7()
    # Detect PLL Lock
    def get_ld(self):
        return( GPIO.input(self.lock_detect_port))
    # set register
    def set_reg1(self,debug=0):
        if(debug):
            print("set reg1")
        self.reg1 = 0x9 | \
            (self.rdiv << 5) | (self.ref_inv << 19) | (self.neg_vco << 20) | \
            (self.icp << 21) | (self.icpdouble << 26) | (self.cal_clk_sel << 27) | (self.rsv << 31)
        self.reg1_l = self.swapbit2byte(self.reg1)
        self.spi.xfer2(self.reg1_l)
    
    def set_reg2(self,debug=0):
        if(debug):
            print("set reg2")
        self.reg2 = 0xa | \
            (self.nint << 5) | (self.pll_div_sel << 21) | (self.prsc_sel << 23) | \
            (self.vco_sel << 26) | (self.vcosel_mode << 28) | (self.cal_acc << 29) | (self.en_cal << 31)
        self.reg2_l = self.swapbit2byte(self.reg2)
        self.spi.xfer2(self.reg2_l)
        
    def set_reg4(self,debug=0):
        if(debug):
            print("set reg4")
        self.reg4 = 0x0c | \
            (self.pwd_pll << 5) | (self.pwd_cp << 6) | ( self.pwd_vco << 7) | \
            (self.pwd_vcomux << 8) | (self.pwd_div124 << 9) | (self.pwd_presc << 10) | \
            (self.pwd_out_buff << 12) | (self.pwd_lo_div << 13) | (self.pwd_tx_div << 14) | \
            (self.pwd_bb_vcm << 15) | (self.pwd_dc_off << 16) | (self.en_ext_vco << 17) | \
            (self.en_isource << 18) | ( self.ld_ana_prec << 19) | (self.cp_tristate << 21) | \
            (self.speedup << 23) | (self.ld_dig_prec << 24) | (self.en_dith << 25) | \
            (self.mod_ord << 26) | (self.dith_sel << 28) | (self.del_sd_clk << 29) | \
            (self.en_frac << 31)
        self.reg4_l = self.swapbit2byte(self.reg4)
        self.spi.xfer2(self.reg4_l)
        
    def set_reg5(self,debug=0):
        if(debug):
            print("set reg5")
        self.reg5 = 0xd | \
            (self.vcobias_rtrim << 5) | (self.pllbias_rtrim << 8) | (self.vco_bias << 10) | \
            (self.vcobuf_bias << 14) | (self.vcomux_bias << 16) | (self.bufout_bias << 18) | \
            (1 << 21) | (self.vco_cal_ib << 22) | ( self.vco_cal_ref << 23) | \
            (self.vco_ampl_ctrl << 26) | (self.vco_vb_ctrl << 28) | (self.en_ld_isource << 31)
        self.reg5_l = self.swapbit2byte(self.reg5)
        self.spi.xfer2(self.reg5_l)
        
    def set_reg6(self,debug=0):
        if(debug):
            print("set reg6")
        self.reg6 = 0xe | \
            (self.ioff << 5) | (self.qoff << 13) | (self.vref_sel << 21) | (self.tx_div_sel << 24) | \
            (self.lo_div_sel << 26) | (self.tx_div_bias << 28) | (self.lo_div_bias << 30)
        self.reg6_l = self.swapbit2byte(self.reg6)
        self.spi.xfer2(self.reg6_l)
        
    def set_reg7(self,debug=0):
        if(debug):
            print("set reg7")
        self.reg7 = 0xf | \
            (self.vco_trim << 7) | (self.vco_test_mode << 14) | (self.cal_bypass << 15) | \
            (self.mux_ctrl << 16) | (self.isource_sink << 19) | (self.isource_trim << 20) | \
            (self.pd_tc << 23) | (self.ib_vcm_sel << 25 ) | (1 << 28 ) | (self.dcoffset_i << 29) | (self.vco_bias_sel) << 31
        self.reg7_l = self.swapbit2byte(self.reg7)
        self.spi.xfer2(self.reg7_l)
        
    ### ......can't read reg0.....
    def get_reg(self,reg_no,debug=0):
        self.reg_no = 0x07 & reg_no
        if(debug):
            print("get reg:",self.reg_no)
        self.reg0 = 0x8 | \
            (self.count_mode_mux_sel << 27) | (self.reg_no << 28) | (1 << 31)   # readback mode
        self.reg0_l = self.swapbit2byte(self.reg0)
        self.spi.xfer2(self.reg0_l)
        self.ret = self.spi.xfer2([0x00,0x00,0x00,0x00])
        return(self.ret)
        
    ########  set modulator/pll/vco parameters ########
    def set_icp(self, icp=10):
        self.icp = 0x1f & icp
        self.set_reg1()
        print("ICP=", self.icp )
    
    def set_frequency(self, freq):
        try:
            if(freq < self.nint_min or freq > self.nint_max):
                raise ValueError("Out of Range and 10kHz Step")
            else:
                self.nint = freq    # 10kHz STEP frequency
                self.set_reg2()
                sleep(0.5)
                print("NINT=", self.nint )
        except ValueError as e:
            print(e)
        
    def set_encal(self):
        self.en_cal = 1 # Resets automatically
        self.set_reg2()
        sleep(0.5)
        print("Execute VCO freq Auto-Calibration:", self.en_cal)
       
    # Reg4
    def set_pwr_pll(self,onoff,detail=False):
        self.pwd_pll = 1 if(onoff.lower() == "off") else 0   # 1=all pll blocks off
        self.set_reg4()
        sleep(0.5)
        if(detail):
            print("PWD_PLL:", self.pwd_pll)
    
    def set_pwr_cp(self,onoff,detail=False):
        self.pwd_cp = 1 if(onoff.lower() == "off") else 0   # 1=charge pump off
        self.set_reg4()
        sleep(0.5)
        if(detail):
            print("PWD_CP:", self.pwd_pll)
        
    def set_pwr_vco(self,onoff,detail=False):
        self.pwd_vco = 1 if(onoff.lower() == "off") else 0   # 1=vco off
        self.set_reg4()
        sleep(0.5)
        if(detail):
            print("PWD_VCO:", self.pwd_vco)
    
    def set_ld_ana_prec(self, prec):
        self.ld_ana_prec = 0x03 & prec
        self.set_reg4()
        print("LD_ANA_PREC:", self.ld_ana_prec)
    
    def set_ld_dig_prec(self, prec):
        self.ld_dig_prec = 0x01 & prec
        self.set_reg4()
        print("LD_DIG_PREC:", self.ld_dig_prec)
        
    def set_pwr_outbuff(self,onoff):
        self.pwd_out_buff = 1 if(onoff.lower() == "off") else 0   # 1=buff off
        self.set_reg4()
        print("PWD_OUT_BUFF:", self.pwd_out_buff)
    
    def set_pwr_lodiv(self,onoff):
        self.pwd_lo_div = 1 if(onoff.lower() == "off") else 0   # 1=tx off
        self.set_reg4()
        print("PWD_LO_DIV:", self.pwd_lo_div)
    
    def set_pwr_txdiv(self,onoff, detail=False):
        self.pwd_tx_div = 1 if(onoff.lower() == "off") else 0   # 1=tx off
        self.set_reg4()
        if(detail):
            print("PWD_TX_DIV:", self.pwd_tx_div)
                
    def set_pwr_bbvcm(self,onoff):
        self.pwd_bb_vcm = 1 if(onoff.lower() == "off") else 0   # 1=tx off
        self.set_reg4()
        print("PWD_BB_VCM:", self.pwd_bb_vcm)
        
    def set_dc_off(self,onoff):
        self.pwd_dc_off = 1 if(onoff.lower() == "off") else 0   # 1=dc offset off
        self.set_reg4()
        print("PWD_DC_OFF:", self.pwd_dc_off)
    # Reg6      
    def set_dc_off_i(self, offset):
        self.ioff = offset
        self.set_reg6()
        print("OFFSET_I: ", self.ioff)
    
    def set_dc_off_q(self, offset):
        self.qoff = offset
        self.set_reg6()
        print("OFFSET_Q: ", self.qoff)

    def get_freq_bits(self):
        print("NINT=", self.nint )
        print("RDIV=", self.rdiv )
    # swap bit order and set byte list
    def swapbit2byte(self, a, debug=0):
        # swap bit
        self.s = bin(a)[2:].zfill(32)
        if(debug):
            print(self.s)
        #print(len(self.s))
        self.ra = self.s[::-1]  # reverse!
        #print(ra)
        self.bytes= []
        for i in range(4):
            self.bits = self.ra[i*8:8+i*8].zfill(8)
            self.bits_i = int(self.bits,2)
            if(debug):
                print( self.bits )
                #print( bits_i )
            self.bytes.append( self.bits_i )
        return(self.bytes)
    
    def __del__(self):
        # Terminate trf operation
        self.set_pwr_txdiv("off")
        self.set_pwr_pll("off")
        self.set_pwr_cp("off")
        self.set_pwr_vco("off")
        # Close SPI
        self.spi.close()
        # Cleanup GPIO
        GPIO.cleanup(self.lock_detect_port)
        GPIO.cleanup(self.cs_reset_port)
        
########
def show_help(trf):
    print("Red prompt is PLL unlock, Green is lock")   
    print("Command List")
    print("icp [0-31]" ,"-> 1.94mA-0.47mA")
    print("freq [", trf.nint_min , "-", trf.nint_max, "]") 
    print("+/-", " -> 10kHz up/down")
    print("tx on|off", "-> tx on/off")
    print("encal", " -> VCO freq Auto Calibration" )
    print("ldana [0-3]", " -> LD_ANA_PREC, 0:high, 3:low" )
    print("lddig [0-1]", " -> LD_DIG_PREC, 0:short, 3:long time" )
    print("pwdpll on|off", "-> power pll on/off")
    print("pwdvco on|off",  "-> power vco on/off")
    print("ioffset  [0-255]", "-> I DC offset")
    print("qoffset  [0-255]",  "-> Q DC offset")

def main():
    on = "on"
    off = "off"
    print("SDR Transmitter starting. rev.f")
    trf = Trf372017(0,0)      # SPI bus=0,device=0
    
    # VCO auto calibration
    trf.set_encal()
    # tx on
    trf.set_pwr_txdiv(on)
    freq = 43300
    trf.set_frequency( freq)
    sleep(1)
    
    # Test
    while(1):
        ld = trf.get_ld()
        #print("LD:",ld)
        p_start = "\033[32m" if (trf.get_ld()) else "\033[31m"   # Lock:Green/ Unlock:Red 
        p_end = "\033[0m"
        p1 = freq
        p2 = ">"
        cmd_line = input( p_start + str(freq) + p2 + p_end)
        cmd = cmd_line.split()

        # frequency
        if( len(cmd)==0):
            pass
        elif(cmd[0] == "freq"):
            freq = int(cmd[1])
            trf.set_frequency(freq)
        elif(cmd[0] == "+"):
            freq += 1
            trf.set_frequency(freq)
        elif(cmd[0] == "-"):
            freq -= 1
            trf.set_frequency(freq)
        # tx on/off
        elif(cmd[0] == "tx"):
            trf.set_pwr_txdiv(on if(cmd[1]=="on") else off)
            print("To generate carrier, I/Q signal is required. For example, play sin/cos sound.")
        # PLL
        elif(cmd[0] == "icp"): # 0=1.94mA, 31=0.47mA, 10=0.97mA
            trf.set_icp( int(cmd[1]))
        elif(cmd[0]=="encal"):
            trf.set_en_cal()
        elif(cmd[0]=="ldana"):
            trf.set_ld_ana_prec( int(cmd[1]))
        # power
        elif(cmd[0]=="pwdpll"):
            trf.set_pwr_pll(on if(cmd[1]=="on") else off)
            print("pwd_pll=", cmd[1])
        elif(cmd[0]=="pwdvco"):
            trf.set_pwr_vco(on if(cmd[1]=="on") else off)
            print("pwd_vco=", cmd[1])
        # I/Q
        elif(cmd[0] == "ioff"): # Iref DC offset
            ioff = 0xff & int(cmd[1])
            trf.set_dc_off_i(ioff)
            print("i_off=", ioff)
        elif(cmd[0] == "qoff"): # Iref DC offset
            qoff = 0xff & int(cmd[1])
            trf.set_dc_off_q(qoff)
            print("q_off=", qoff)
        #
        elif(cmd[0] == "qoff"): # Iref DC offset
            qoff = 0xff & int(cmd[1])
            trf.set_dc_off_q(qoff)
            print("q_off=", qoff)
        # help
        elif(cmd[0]=="?" or cmd[0]=="help" or cmd[0]=="h"):
            show_help(trf)
        # re-start
        elif(cmd[0]=="init"):
            del trf
            sleep(1)
            trf = Trf372017(0,0)      # Re-born
        # Quit
        elif(cmd[0]=="quit" or cmd[0]=="exit" or cmd[0]=="q" or cmd[0]=="e"):
            del trf
            print("Bye!")
            exit()
        else:
            print("???")
            show_help(trf)
    
if __name__ == '__main__':    
    main()

# end of trf372017_raspi.py

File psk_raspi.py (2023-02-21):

#!/usr/bin/env python3
# -*- coding: UTF-8 -*-
#
# psk_raspi.py
#
# This program is for SDR_Transmit_Hat(My own work, See hat directory)
# Generate/transmit BPSK, QPSK, pi/2 Shift BPSK, pi/4 Shift QPSK, OQPSK
# Symbol rate is (192k)/N (N>=3, 2 might work).
# Sampling rate is 192kHz.
# I/Q signal is provided through i2s on raspi
# I2S port in raspi board must be enabled and set default sound device. 
#
# Required file: trf372017_raspy.py and ctrl_trf372017.py in the same directory.
#
# This implementation is for personal experiments.
#
# Copyright (c) 2022-2023 Tsuyoshi Ohashi
# Released under the MIT license
# https://opensource.org/licenses/mit-license.php
#  

import numpy as np
import sys
import os
import matplotlib.pyplot as plt
import commpy as cp

#import pyaudio
import sounddevice as sd
#import threading

class PskMod:

    gain_default = 0.5
    
    def __init__(self,gain=0.5, mod="bpsk",fs=192000,sps=6,alpha=0.35,n_tap=11):
        self.gain = gain    # IQ signal is about 0.4V at trf372
        self.fs = fs         # sampling frequency (48000,96000,192000)
        self.sps = sps       # samples per symbol
        self.aplha = alpha  
        self.tap = n_tap*sps
        self.ts = 1/fs*sps  # symbol period
        self.sr = int(fs/sps)    # symbol rate
        self.mod = mod
        if(self.mod=="bpsk"):
            # bpsk modulator has 2 symbols
            self.psk_mod = cp.modulation.PSKModem(2)
        elif(self.mod=="qpsk"):
            # qpsk modulator has 4 symbols
            self.psk_mod = cp.modulation.PSKModem(4)
    
    def set_gain(self, gain):
        if(gain>=0 and gain <=1):
            self.gain = gain
    
    def __call__(self,bits,disp_l):
        self.modulate(bits,disp_l)
    
    # oqpsk modulator
    def oq_mod(self, bits):
        self.bits = bits
        self.len = np.sqrt(2)/2
        self.symbols = np.array([], dtype=np.complex64)    # array for modulation symbols
        
        self.sym = 1 + 1j # start with dummy symbol 
        self.symbols = np.append(self.symbols, self.sym)
        for i in range(0, len(self.bits), 2):
            if(self.bits[i]==0 ):
                self.sym = 1 + self.symbols[-1].imag*1j
            else:
                self.sym = -1 + self.symbols[-1].imag*1j
            self.symbols = np.append(self.symbols, self.sym)
            #print(i, self.bits[i], self.sym)
            
            if(self.bits[i+1]==0 ):
                self.sym = self.symbols[-1].real +1j
            else:
                self.sym = self.symbols[-1].real -1j
            self.symbols = np.append(self.symbols, self.sym)
            #print(i+1, self.bits[i+1], self.sym)
        return(self.symbols)
        
    # pi/4 shift qpsk modulator
    def pi4_mod(self, bits):
        self.bits = bits
        self.len = np.sqrt(2)/2
        self.sym_table = {0:1, 1:(1+1j)*self.len, 2:1j, 3:(-1+1j)*self.len, 4:-1, 5:(-1-1j)*self.len, 6:-1j, 7:(1-1j)*self.len}
        self.symbols = np.array([])    # array for modulation symbols

        self.phase = 0  # Phase absolute location
        for i in range(0, len(self.bits), 2):
            if(self.bits[i]==0 and self.bits[i+1]==0):      # 1/4
                self.phase += 1
            elif(self.bits[i]==0 and self.bits[i+1]==1):    # 3/4
                self.phase += 3
            elif(self.bits[i]==1 and self.bits[i+1]==0):    # -1/4
                self.phase += 7
            else:                                           # -3/4
                self.phase += 5
            self.phase = self.phase % 8
            self.sym = self.sym_table[self.phase]
            #print(self.bits[i],self.bits[i+1], self.phase, self.sym)
            self.symbols = np.append(self.symbols, self.sym)
        return(self.symbols)

    # pi/2 shift bpsk modulator
    def pi2_mod(self,bits):
        self.bits = bits
        
        self.sym_table = {0:1, 1:1j, 2:-1, 3:-1j}
        self.symbols = np.array([])    # array for modulation symbols

        self.phase = 0  # Phase absolute location
        for i in range(0, len(self.bits)):
            if(self.bits[i]==0):      # 1/2
                self.phase += 1
            else:                     # -1/2
                self.phase += 3
            self.phase = self.phase % 4
            self.sym = self.sym_table[self.phase]
            #print(self.bits[i], self.phase, self.sym)
            self.symbols = np.append(self.symbols, self.sym)
        return(self.symbols)

    # make symbol / up sampling / rrc filter / transmit through sound / display wave, constellation
    def modulate(self, bits, disp_l=0):
        self.bits = bits
        self.disp_l = disp_l
        #print(self.bits)
        
        # bpsk/ qpsk
        if(self.mod=="bpsk" or self.mod=="qpsk"):
            # modulate bit into IQ symbols
            self.symbols = self.psk_mod.modulate(self.bits)
        # pi/2 shift bpsk
        elif(self.mod=="pi2bpsk"):
            self.symbols = self.pi2_mod(self.bits)
        # pi/4 shift qpsk
        elif(self.mod=="pi4qpsk"):
            self.symbols = self.pi4_mod(self.bits)
        # oqpsk
        elif(self.mod=="oqpsk"):
            self.symbols = self.oq_mod(self.bits)
        else:
            print("unkown modulation type")
            return(False)
        # up-conversion
        #self.symbols_upsampled = np.zeros(self.sps*(len(self.symbols)-1)+1,dtype = np.complex64) 
        #self.symbols_upsampled[::self.sps] = self.symbols
        self.symbols_upsampled = cp.utilities.upsample(self.symbols, self.sps)
        #print(len(self.symbols))
        #print(self.symbols_upsampled)
        
        # RRC filter
        self.rrc_filter = cp.filters.rrcosfilter(self.tap, alpha=self.aplha, Ts=self.ts, Fs=self.fs)[1]
        # Complex signal
        self.signal = np.convolve(self.rrc_filter, self.symbols_upsampled)
        # get IQ signal and adjust gain
        self.sig_i = self.signal.real * self.gain
        self.sig_q = self.signal.imag * self.gain
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

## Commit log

2022-12-20 add parts list
    [all_mode_tx_3.csv]
2022-12-20 add KLicad Schematic
    [all_mode_tx_3.kicad_sch, diff_amp.kicad_sch, i2s_2.kicad_sch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]
2022-12-28 Create t=1.2mm
    add pcb thickness
